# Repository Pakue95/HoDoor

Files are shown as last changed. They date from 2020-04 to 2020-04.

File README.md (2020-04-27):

HoDoor is an access control board that uses RFID (13.56MHz) to authenticate users e.g. to enter restricted areas. The firmware repository can be found [here]() (to be released).

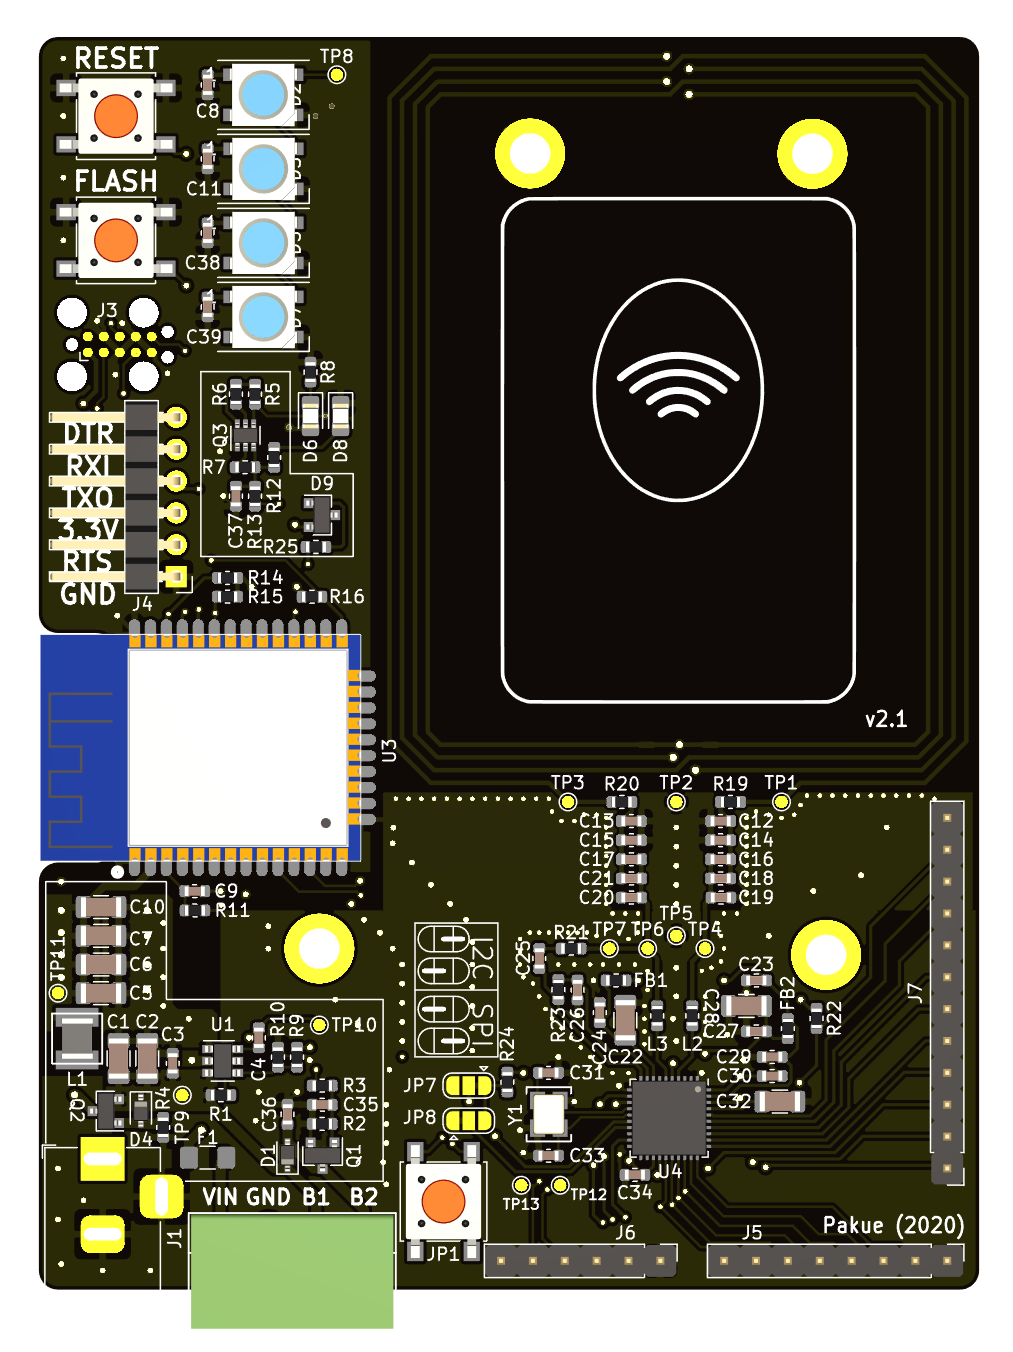
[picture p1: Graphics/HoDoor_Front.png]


## ToDo
* generate Gerber files
* generate new 3d STEP files
* update case-files to v2.1

The work is release as is without any warranties or guarantees. Use on your own risk.

## Hardware
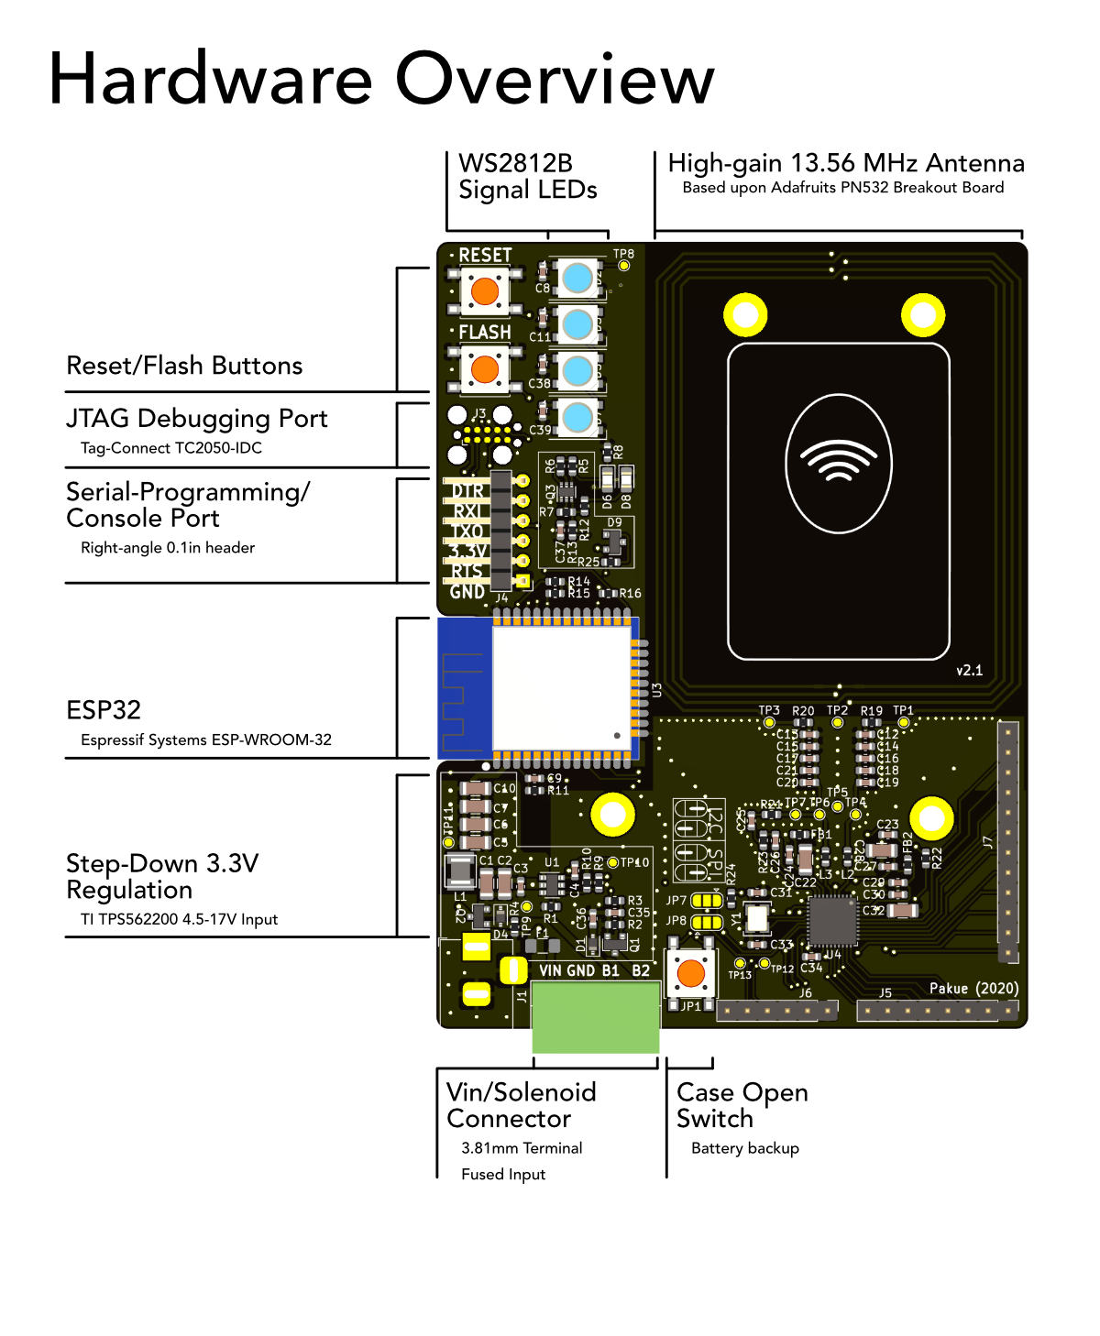
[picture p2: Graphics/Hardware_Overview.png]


## License

Designed by Patrick Kübler (except for Adafruit PN532 Shield part). Creative Commons Attribution/Share-Alike.

### Adafruit PN532 RFID/NFC Shield for Arduino

The NFC part of the board is based upon the Adafruit PN532 RFID/NFC Shield for Arduino. The design files can be found in the according [repository](https://github.com/adafruit/Adafruit-PN532-RFID-NFC-Shield) and the board can be purchased from [Adafruit](https://www.adafruit.com/product/789).

Following changes were made from the Adafruit design:
* Moved pinheader around (no Arduino Shield compatebility anymore)
* Moved some components and routing
* removed LED power indicator
* no prototyping area
* removed 3.3V regulator (handled by the HoDoor board)

**README from Adafruit PN532 Shield**

>We've taken our popular Adafruit PN532 breakout board and turned it into a shield - the perfect tool for any 13.56MHz RFID or NFC application. The Adafruit NFC shield uses the PN532 chip-set (the most popular NFC chip on the market) and is what is embedded in pretty much every phone or device that does NFC. It can pretty much do it all, such as read and write to tags and cards, communicate with phones (say for payment processing), and 'act' like a NFC tag. If you want to do any sort of embedded NFC work, this is the chip you'll want to use!

>These are the Eagle CAD files for the Adafruit PN532 RFID/NFC Shield for Arduino:

>* http://www.adafruit.com/products/789

>License

>Adafruit invests time and resources providing this open source design, please support Adafruit and open-source hardware by purchasing products from Adafruit!

>All text above must be included in any redistribution

>Designed by Limor Fried/Ladyada and Kevin Townsend for Adafruit Industries. Creative Commons Attribution/Share-Alike, all text above must be included in any redistribution. See license.txt for additional information.

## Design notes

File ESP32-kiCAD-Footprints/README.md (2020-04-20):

from [ESP32-kiCAD-Footprints by adamjvr](https://github.com/adamjvr/ESP32-kiCAD-Footprints)

# ESP32-kiCAD-Footprints

Footprints for the Espressif ESP32 WiFi/BLE Chip and ESP3212 module, for KiCAD EDA
These footprints are current untested use at your own risk! I'll have a test board
soon!

Now includes an alternate esp32-xess.lib schematic library in which the
pin types of the ESP32 chip and modules have been changed to reflect their
actual functions (before they were all set as inputs).
This library also includes a symbol for the ESP32 chip that has the pins arranged
like the 48-pin QFN package.

ESP3212 - Module
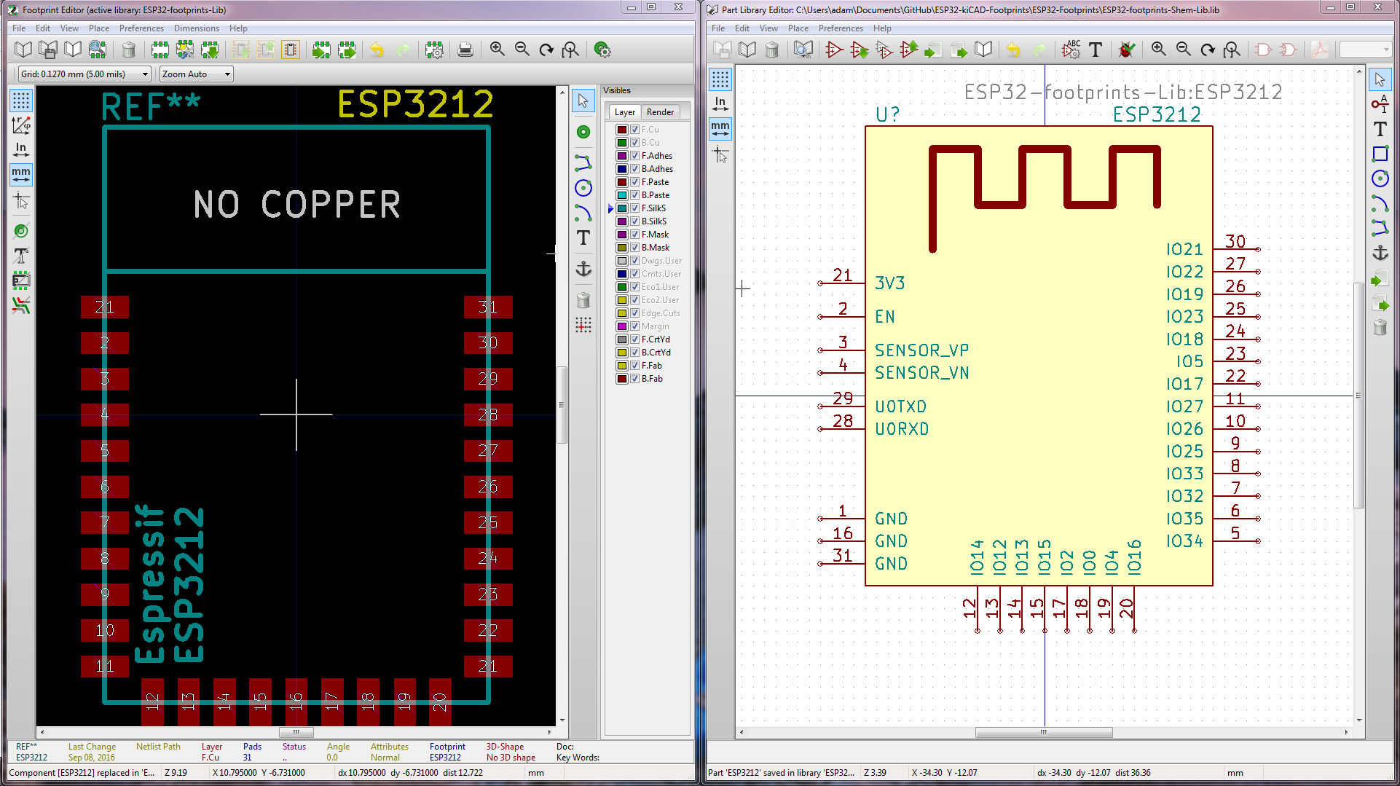
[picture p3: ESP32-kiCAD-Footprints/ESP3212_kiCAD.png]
ESP3212 - Module


ESP32-WROOM - module
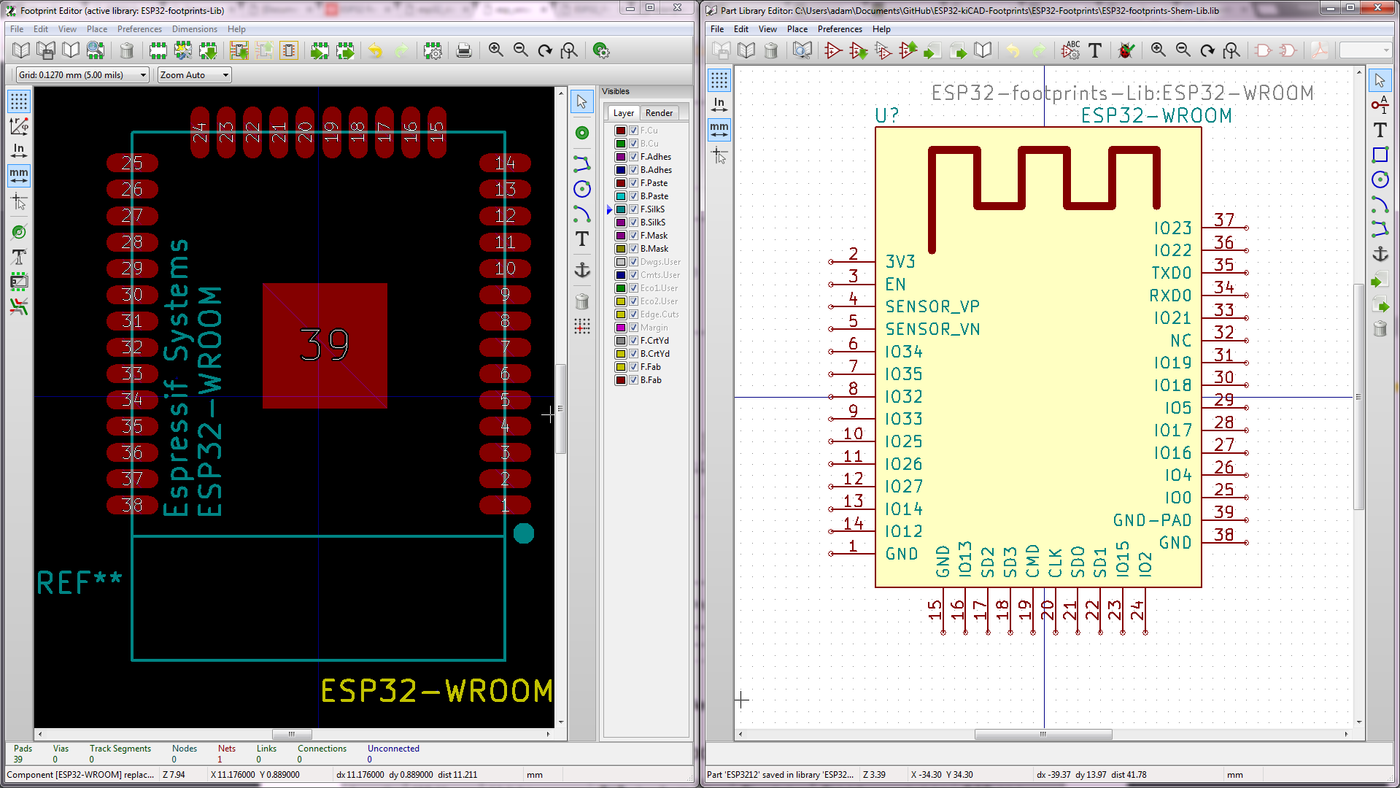
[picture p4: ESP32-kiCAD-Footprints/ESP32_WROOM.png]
ESP32-WROOM - module


ESP32 - 48 Pin QFN IC
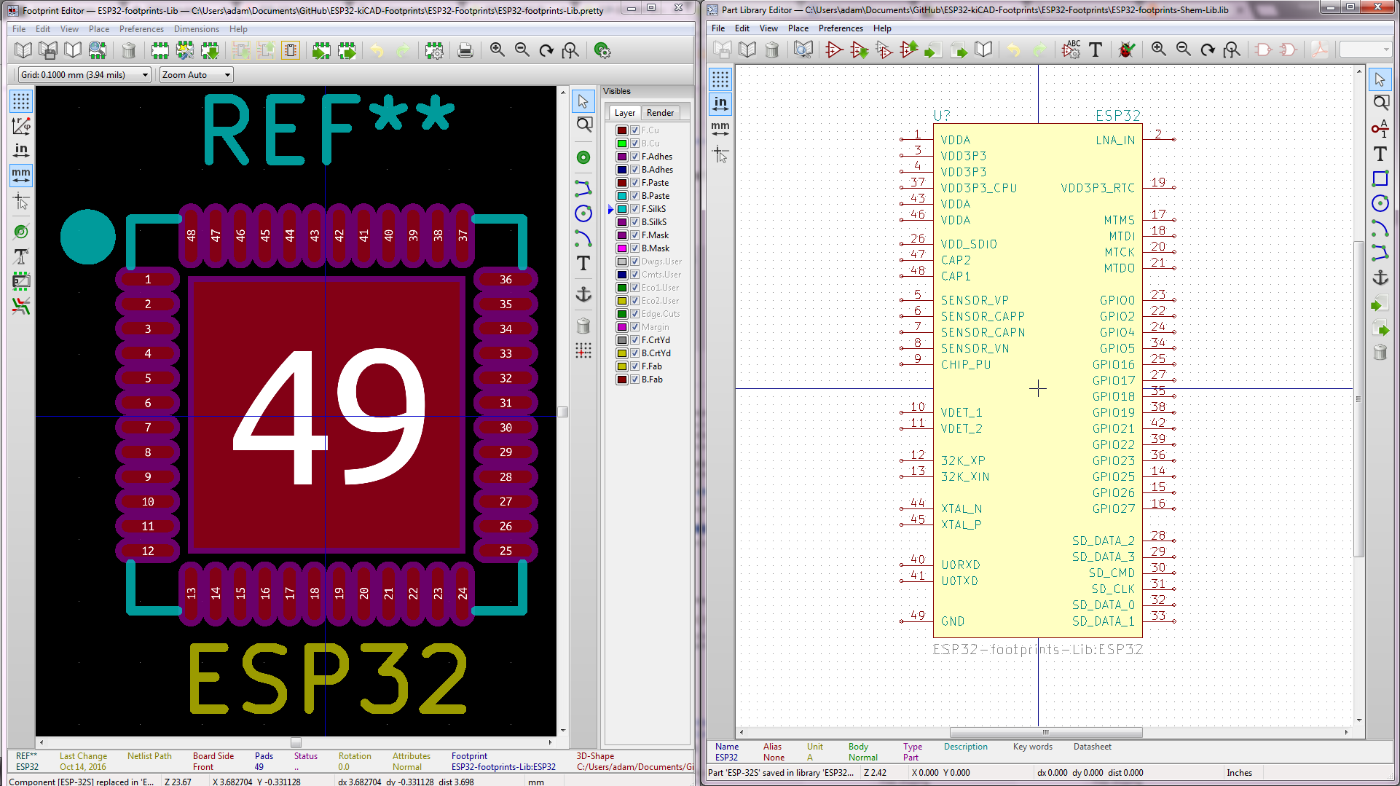
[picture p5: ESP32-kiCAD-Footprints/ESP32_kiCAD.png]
ESP32 - IC


ESP32 - 48 Pin QFN IC (XESS)
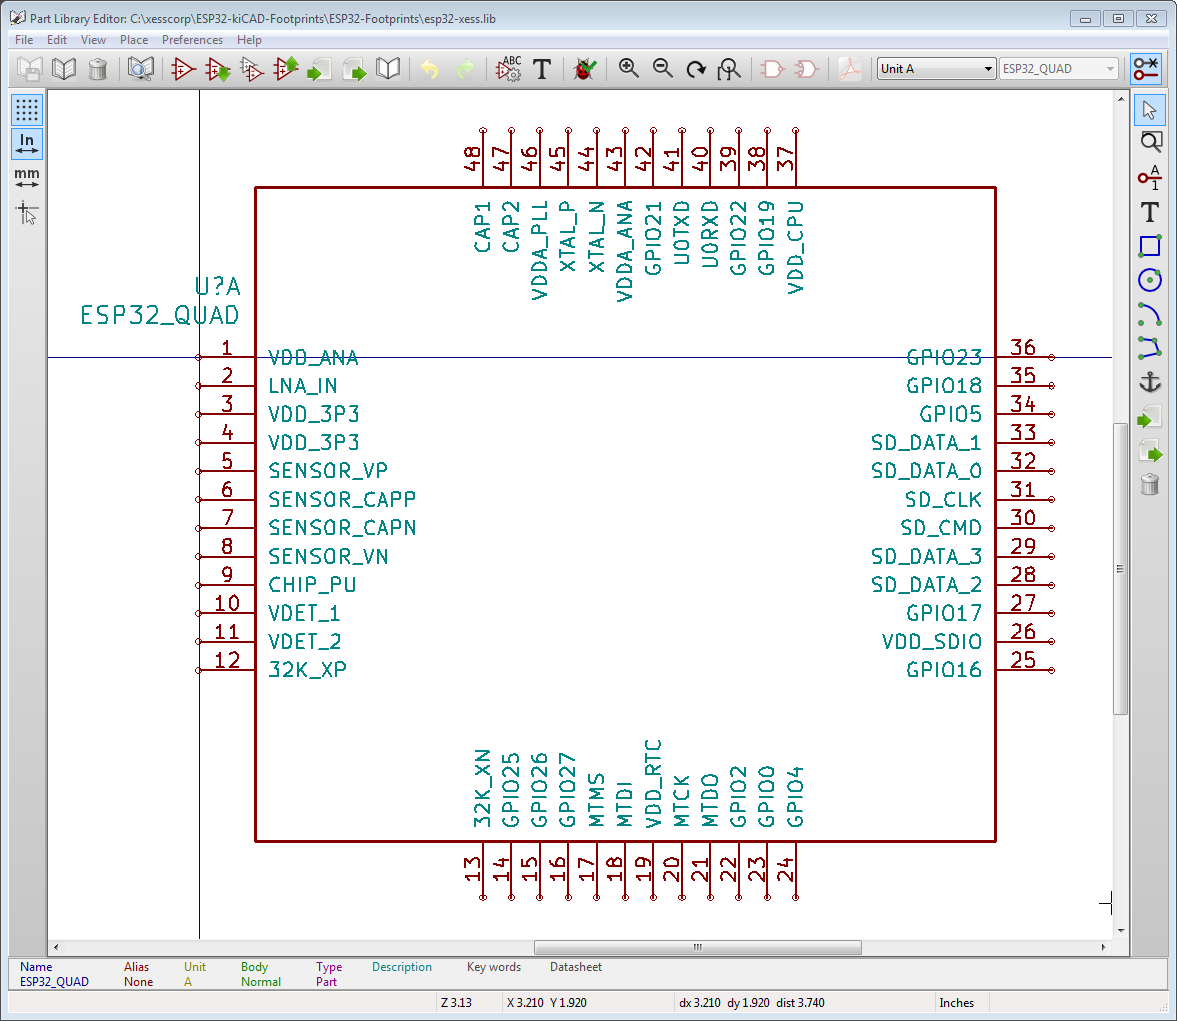
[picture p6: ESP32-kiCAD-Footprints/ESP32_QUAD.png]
ESP32 - IC - XESS


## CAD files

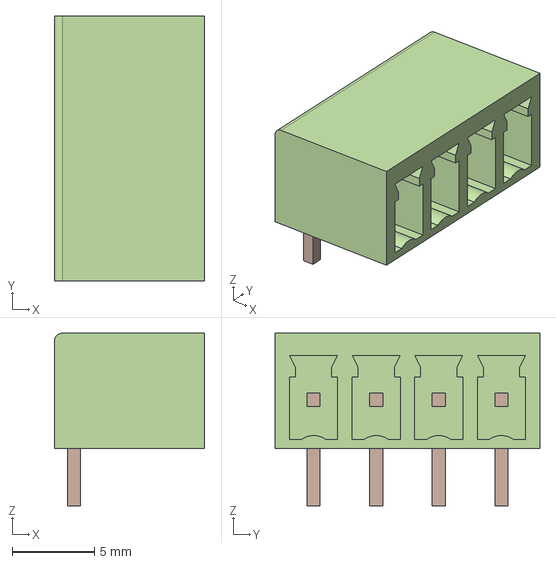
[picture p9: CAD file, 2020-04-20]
3d/WJ15EDGRC-3.81-4P.step
9.15 x 16.1 x 10.5 mm

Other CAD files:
3d/WJ15EDGRC-3.81-4P.FCStd

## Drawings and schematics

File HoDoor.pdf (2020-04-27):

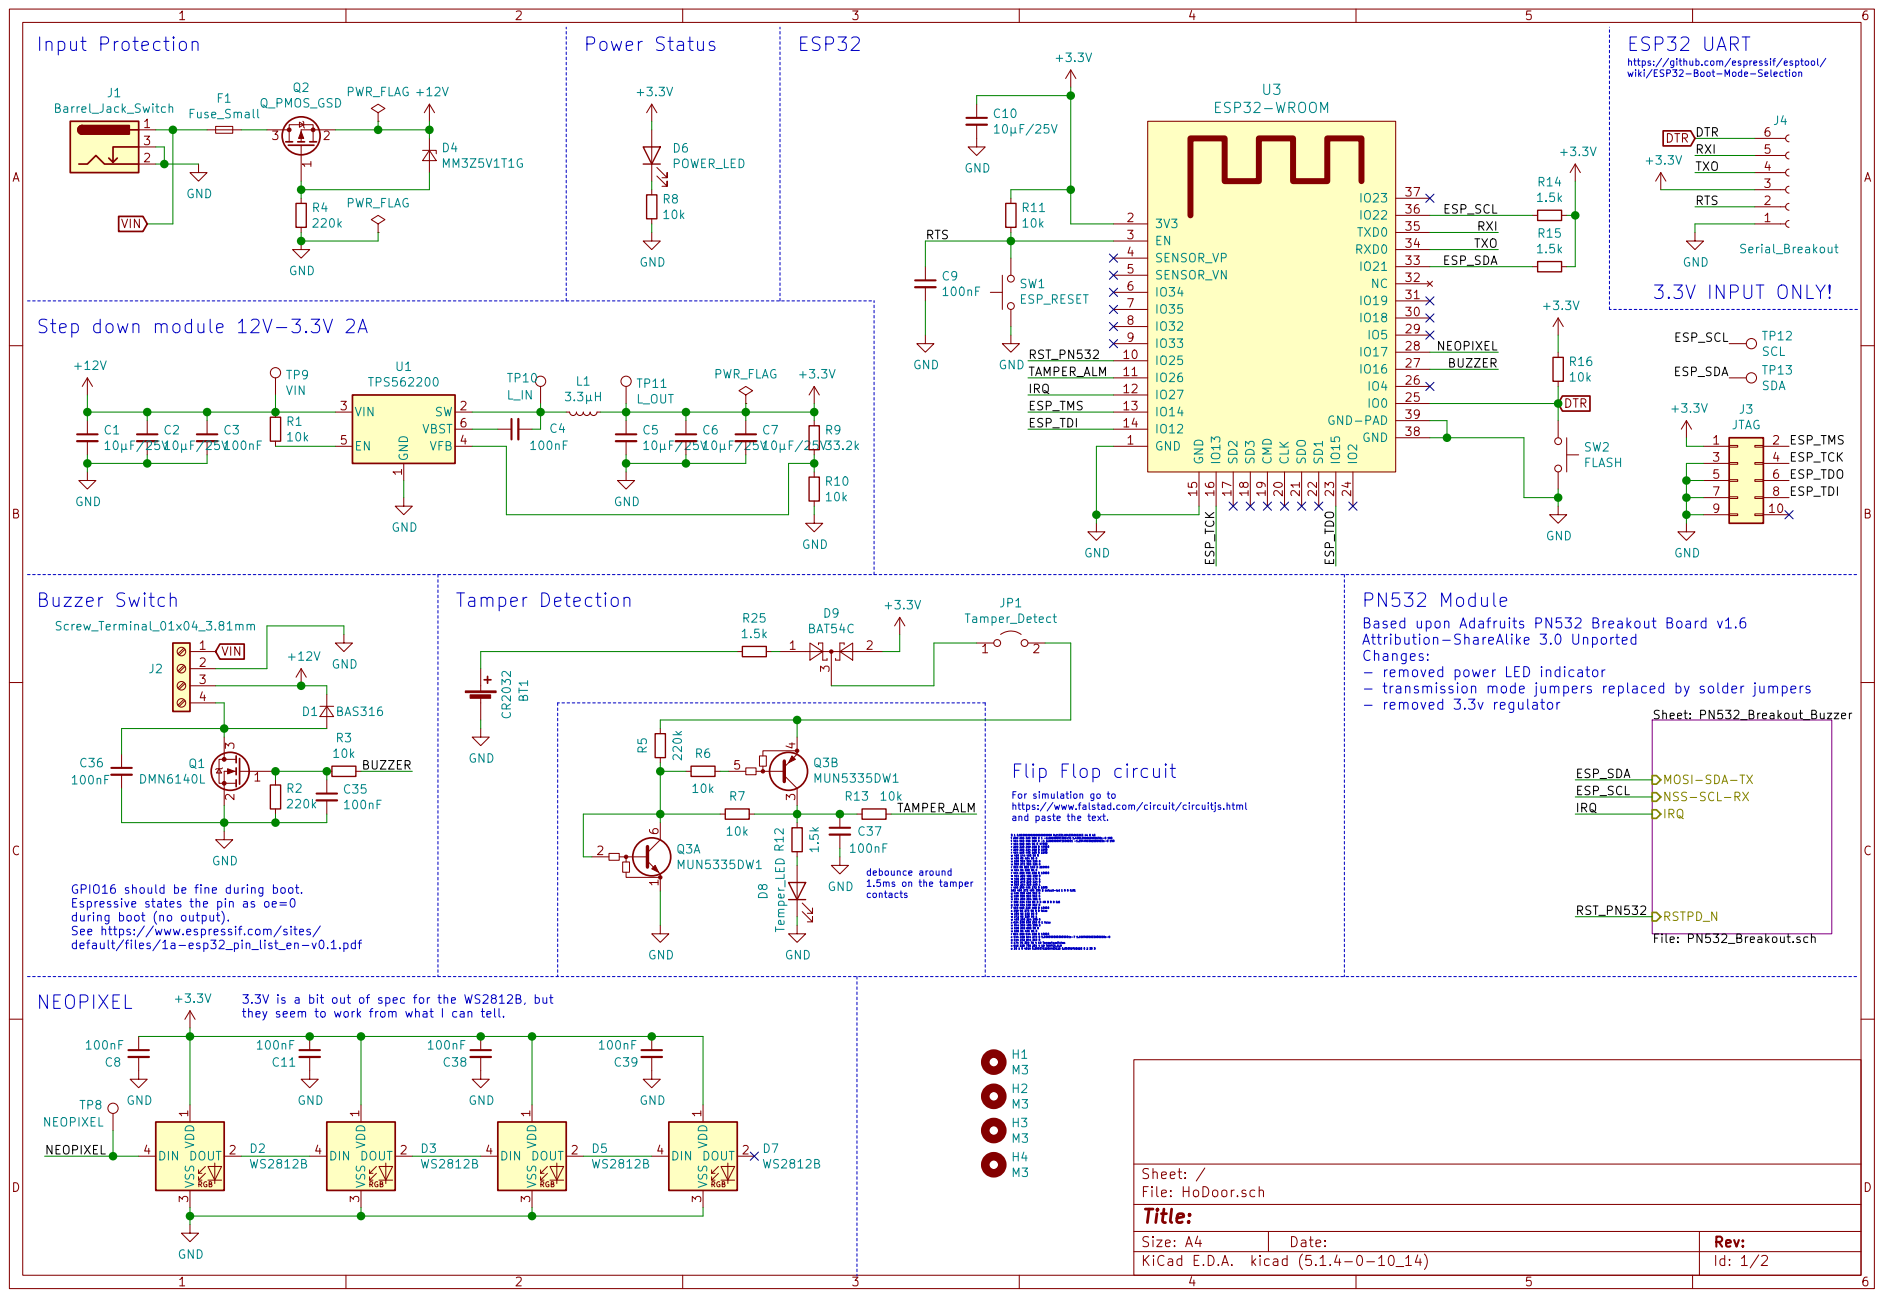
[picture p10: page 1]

https://github.com/espressif/esptool/ wiki/ESP32-Boot-Mode-Selection

debounce around 1.5ms on the tamper contacts Step down module 12V-3.3V 2A

1 SW 2 VIN 3 VFB 4 EN 5 VBST 6 U1 TPS562200 C3

Based upon Adafruits PN532 Breakout Board v1.6
Attribution-ShareAlike 3.0 Unported
Changes:
- removed power LED indicator
- transmission mode jumpers replaced by solder jumpers
- removed 3.3v regulator

For simulation go to https://www.falstad.com/circuit/circuitjs.html and paste the text.

GPIO16 should be fine during boot.
Espressive states the pin as oe=0
during boot (no output).
See https://www.espressif.com/sites/
default/files/1a-esp32_pin_list_en-v0.1.pdf

3.3V is a bit out of spec for the WS2812B, but
they seem to work from what I can tell.

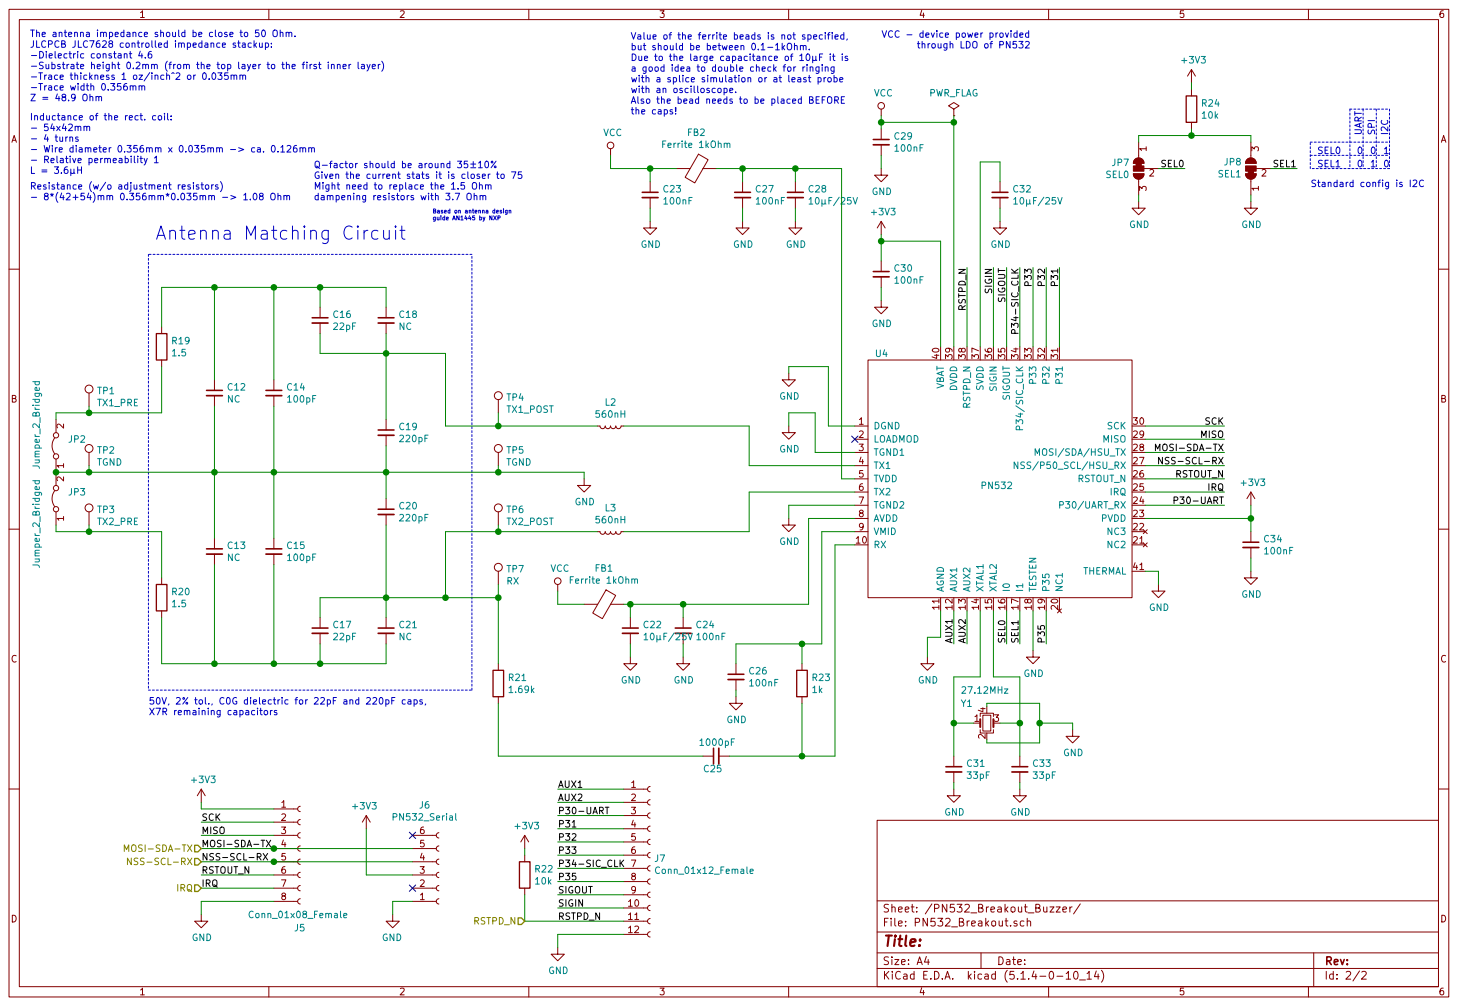
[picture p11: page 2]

Also the bead needs to be placed BEFORE

The antenna impedance should be close to 50 Ohm.
JLCPCB JLC7628 controlled impedance stackup: -Dielectric constant 4.6

Value of the ferrite beads is not specified, but should be between 0.1-1kOhm. Due to the large capacitance of 10µF it is

VCC - device power provided
through LDO of PN532
SEL1 RSTOUT_N

-Substrate height 0.2mm (from the top layer to the first inner layer)
-Trace thickness 1 oz/inch^2 or 0.035mm
-Trace width 0.356mm
Inductance of the rect. coil: - 54x42mm

a good idea to double check for ringing
with a splice simulation or at least probe
with an oscilloscope.

the caps! Based on antenna design guide AN1445 by NXP Q-factor should be around 35±10%

Given the current stats it is closer to 75 Might need to replace the 1.5 Ohm

dampening resistors with 3.7 Ohm

50V, 2% tol., C0G dielectric for 22pF and 220pF caps,
X7R remaining capacitors

SCK MISO MOSI-SDA-TX NSS-SCL-RX RSTOUT_N

IRQ MOSI-SDA-TX

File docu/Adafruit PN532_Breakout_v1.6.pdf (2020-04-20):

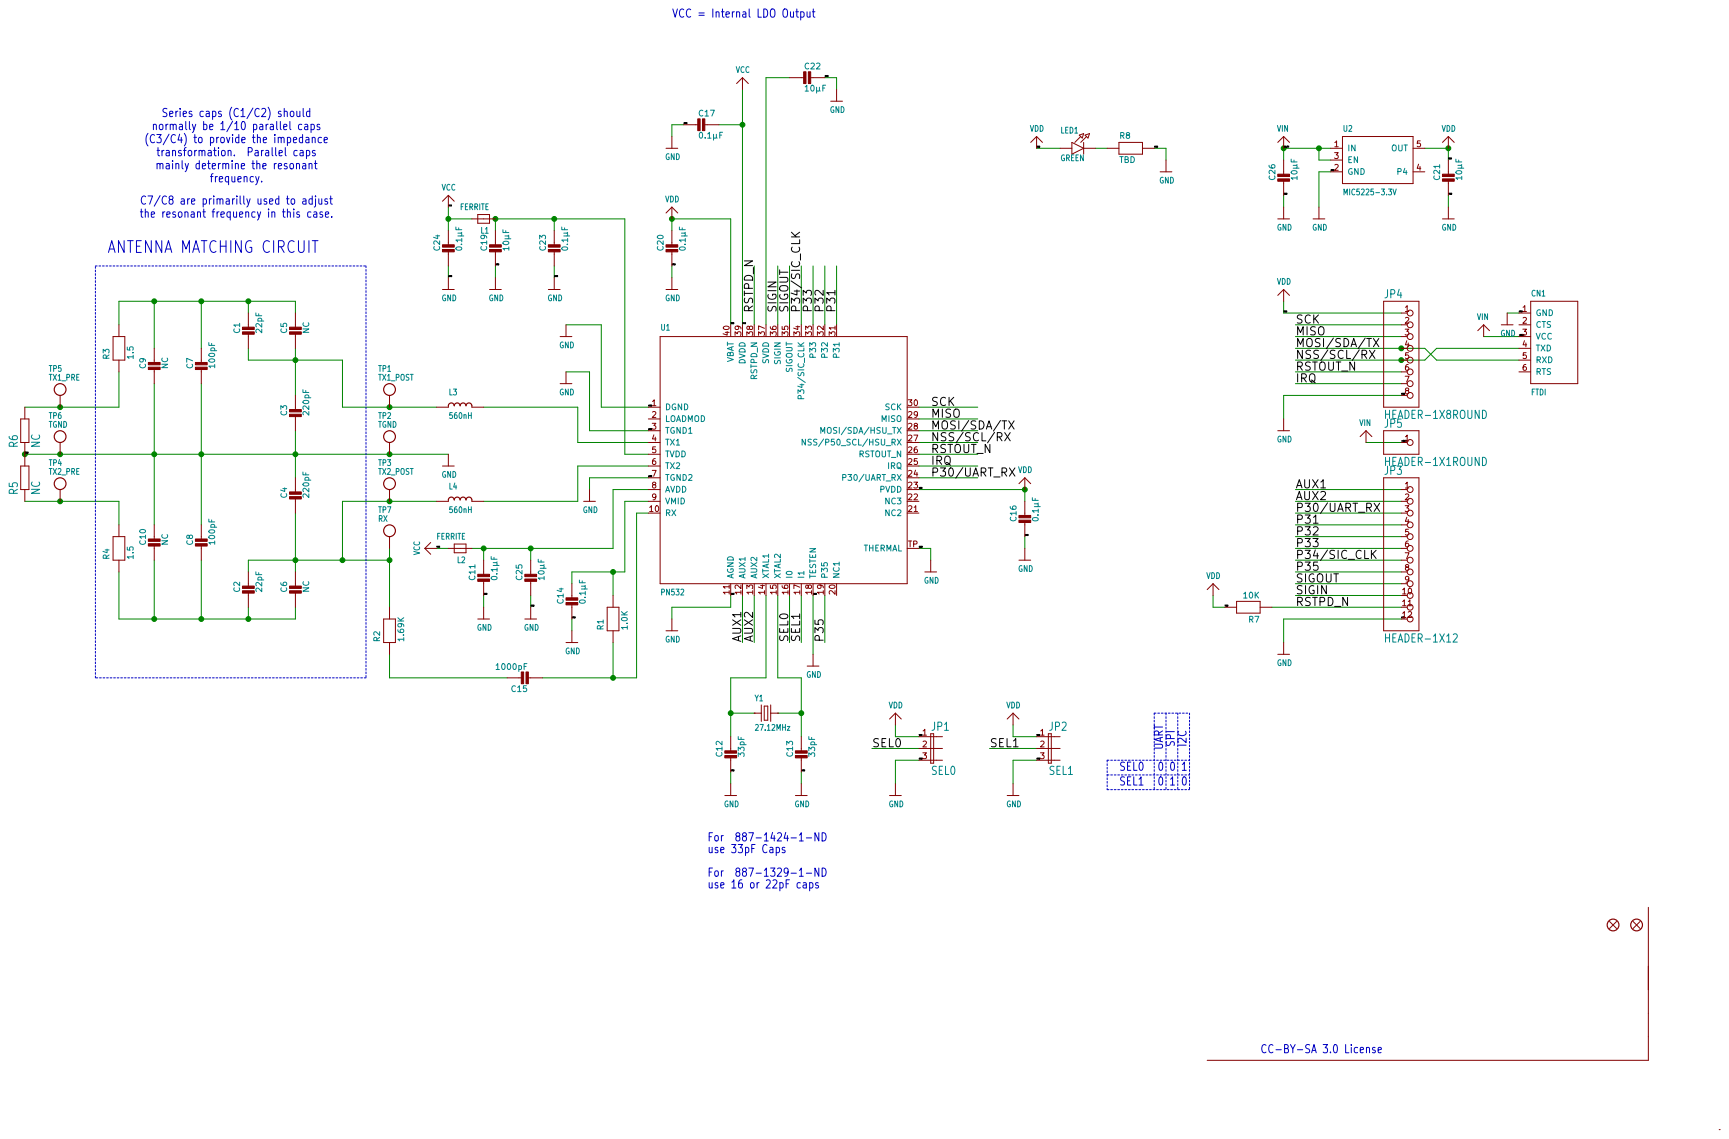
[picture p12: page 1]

VCC = Internal LDO Output

Series caps (C1/C2) should
normally be 1/10 parallel caps
(C3/C4) to provide the impedance
transformation. Parallel caps
mainly determine the resonant

C7/C8 are primarilly used to adjust
the resonant frequency in this case.
ANTENNA MATCHING CIRCUIT

SEL0 | 0 | 0 | 1

CC-BY-SA 3.0 License

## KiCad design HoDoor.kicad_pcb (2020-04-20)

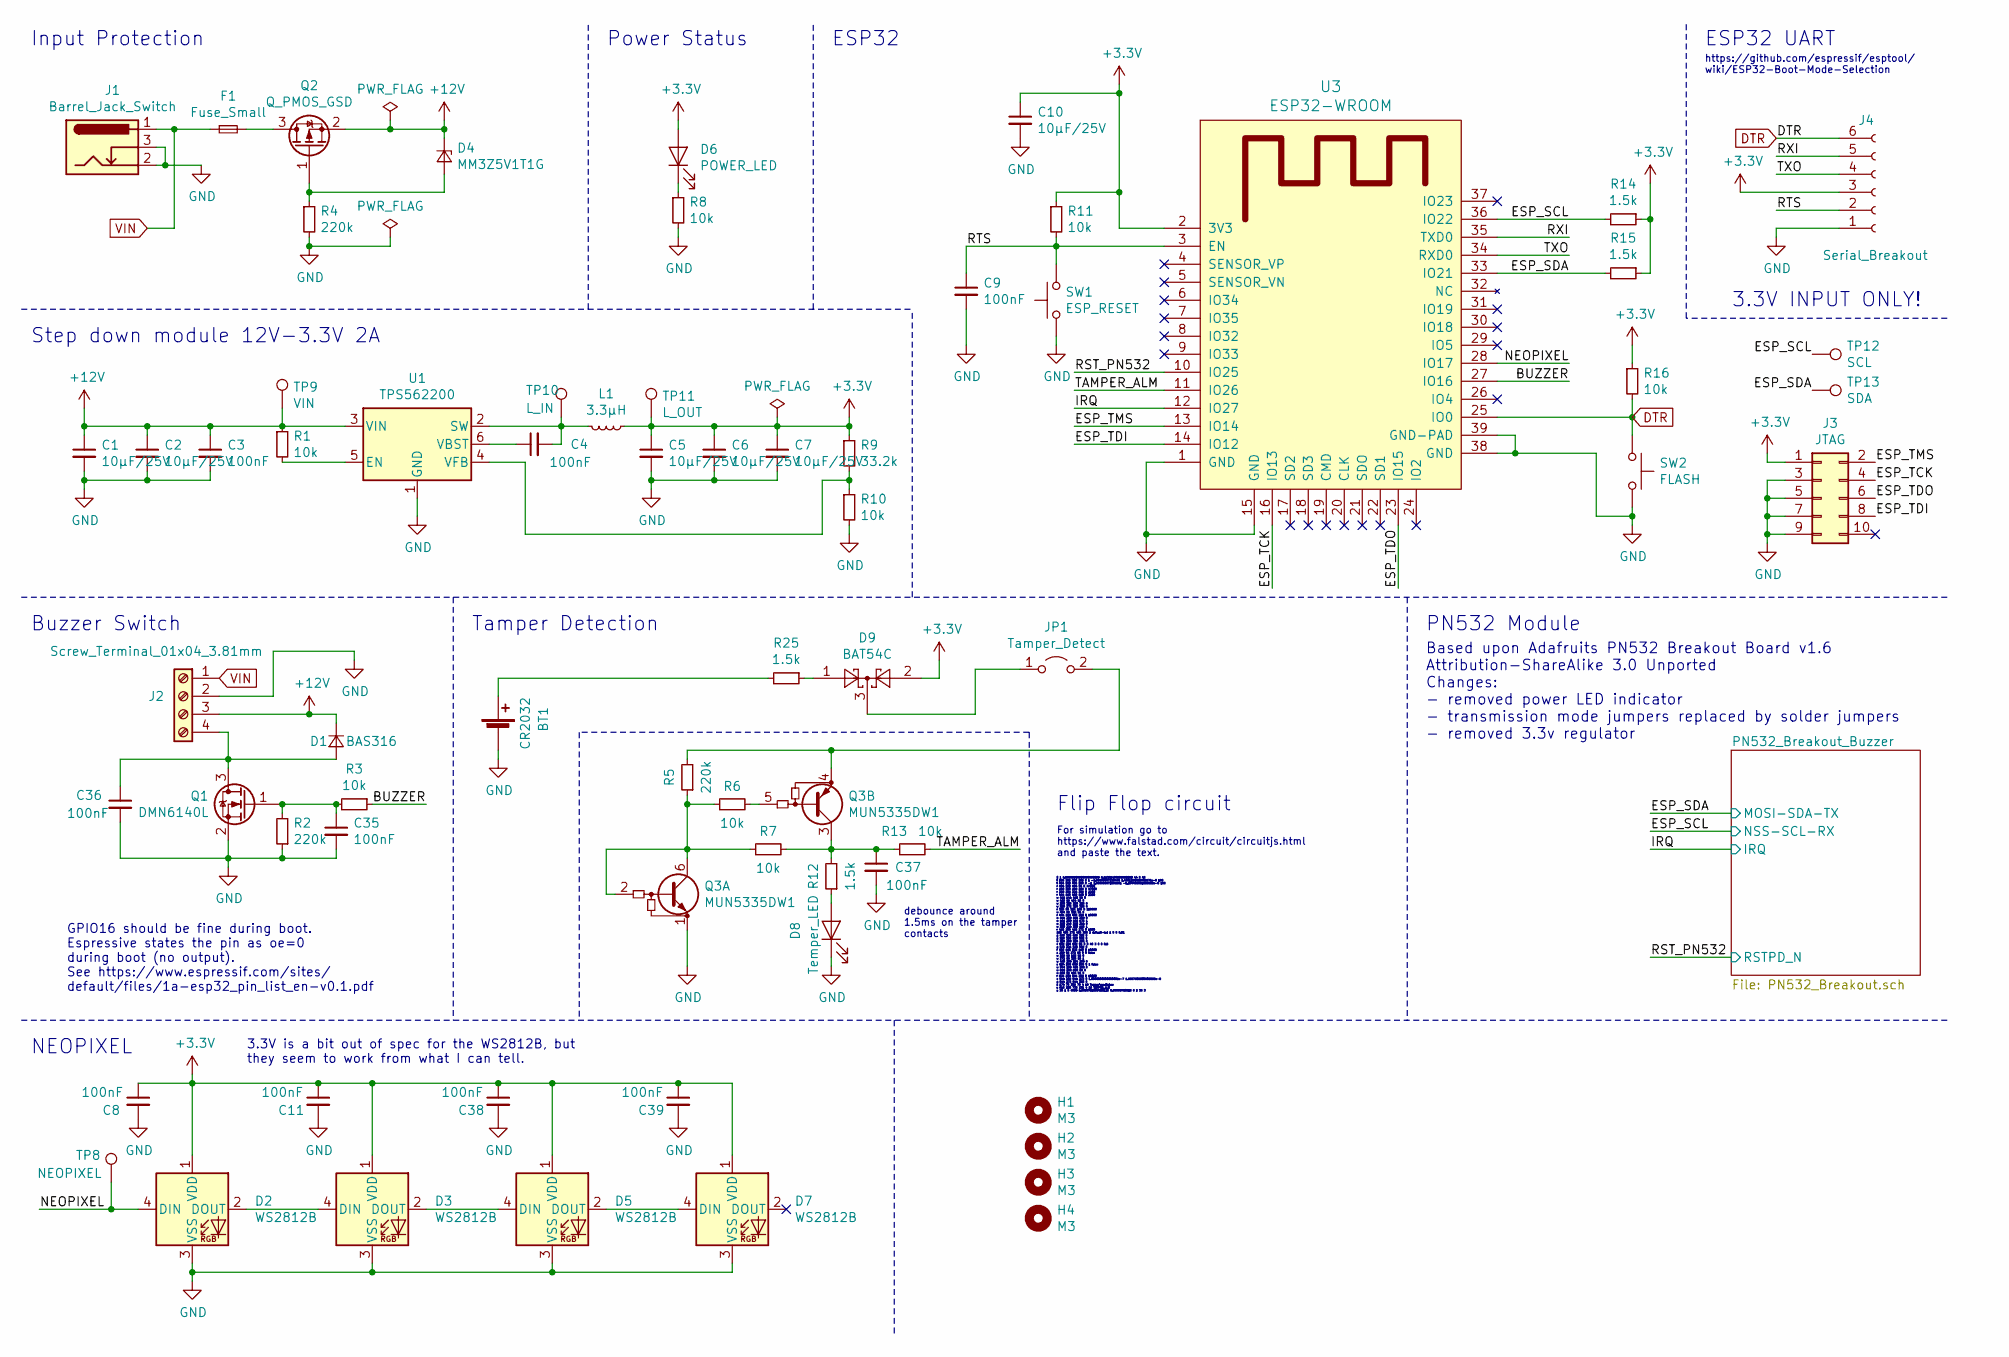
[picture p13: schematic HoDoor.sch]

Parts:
BT1: CR2032; BatteryHolder_Keystone_1060_1x2032; Part CR2032-BS-6-1; LCSC C70377
C1, C2, C5, C6, C7, C10: 10µF/25V; C_1206_3216Metric; Part CL31B106KAHVPNE; LCSC C9807
C3, C4, C8, C9, C11, C35, C36, C37, C38, C39: 100nF; C_0603_1608Metric; Part CL10B104KA8NNNC; LCSC C1590
D1: BAS316; D_SOD-323; Part BAS316,115; LCSC C109218
D2, D3, D5, D7: WS2812B; LED_WS2812B_PLCC4_5.0x5.0mm_P3.2mm
D4: MM3Z5V1T1G; D_SOD-323; Part MM3Z5V1T1G; LCSC C75074
D6: POWER_LED; LED_0805_2012Metric_Pad1.15x1.40mm_HandSolder; Part FC-2012HRK-620D; LCSC C84256
D8: Temper_LED; LED_0805_2012Metric_Pad1.15x1.40mm_HandSolder; Part TJ-S2012SW8TGLC0A-A5 TJ-S2012SW8TGLC0A-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; LCSC C192670
D9: BAT54C; SOT-23; LCSC C37704
F1: Fuse_Small; Fuse_1206_3216Metric_Pad1.42x1.75mm_HandSolder
H1, H2, H3, H4: M3; MountingHole_3.2mm_M3_DIN965_Pad
J1: Barrel_Jack_Switch; BarrelJack_Horizontal
J2: Screw_Terminal_01x04_3.81mm; WJ15EDGRC-3.81-4P; Part WJ15EDGRC-3.81-4P + WJ15EDGKB-3.81-4P; LCSC C7245 + C8408
J3: JTAG; Tag-Connect_TC2050-IDC-FP_2x05_P1.27mm_Vertical
J4: Serial_Breakout; PinHeader_1x06_P2.54mm_Horizontal; Part A2541WR-6P; LCSC C225492
JP1: Tamper_Detect; SW_SPST_B3S-1000
L1: 3.3µH; NPIS43LS; Part NPIS43LS3R3MTRF
Q1: DMN6140L; SOT-23; Part DMN6140LQ-7; LCSC C155271
Q2: Q_PMOS_GSD; SOT-23; Part AO3401A; LCSC C15127
Q3: MUN5335DW1; SOT-363_SC-70-6; Part MUN5335DW1T1G; LCSC C99680
R1, R3, R6, R7, R10, R11, R13, R16: 10k; R_0603_1608Metric; Part RC0603FR-0710KL; LCSC C98220
R2, R4, R5: 220k; R_0603_1608Metric; Part RC0603FR-07220KL; LCSC C123420
R8: 10k; R_0603_1608Metric; Part RC0603JR-07330RL; LCSC C105879
R9: 33.2k; R_0603_1608Metric; Part AC0603FR-0733K2L; LCSC C227824
R12, R14, R15, R25: 1.5k; R_0603_1608Metric; Part RC0603FR-071K5L; LCSC C114668
SW1: ESP_RESET; SW_SPST_B3S-1000; Part TSA063G43-250; LCSC C294564
SW2: FLASH; SW_SPST_B3S-1000; Part TSA063G43-250; LCSC C294564
TP8: NEOPIXEL; TestPoint_Pad_D1.0mm
TP9: VIN; TestPoint_Pad_D1.0mm
TP10: L_IN; TestPoint_Pad_D1.0mm
TP11: L_OUT; TestPoint_Pad_D1.0mm
TP12: SCL; TestPoint_Pad_D1.0mm
TP13: SDA; TestPoint_Pad_D1.0mm
U1: TPS562200; SOT-23-6; Part TPS562200DDCR; LCSC C49757
U3: ESP32-WROOM

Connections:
+12V: C1.1, C2.1, C3.1, D1.1 (K), D4.1 (K), J2.3, Q2.2 (S), R1.1, TP9.1, U1.3 (VIN)
/BUZZER: R3.1, U3.27 (IO16)
/ESP_SCL: R14.2, TP12.1, U3.36 (IO22); also elsewhere on the board
/ESP_SDA: R15.2, TP13.1, U3.33 (IO21); also elsewhere on the board
/ESP_TCK: J3.4, U3.16 (IO13)
/ESP_TDI: J3.8, U3.14 (IO12)
/ESP_TDO: J3.6, U3.23 (IO15)
/ESP_TMS: J3.2, U3.13 (IO14)
/IRQ: U3.12 (IO27); also elsewhere on the board
/NEOPIXEL: D2.4 (DIN), TP8.1, U3.28 (IO17)
/RST_PN532: U3.10 (IO25); also elsewhere on the board
/RTS: C9.1, J4.2, R11.2, SW1.2, U3.3 (EN)
/RXI: J4.5, U3.35 (TXD0)
/TAMPER_ALM: R13.2, U3.11 (IO26)
/TXO: J4.4, U3.34 (RXD0)
DTR: J4.6, R16.2, SW2.1, U3.25 (IO0)
GND: BT1.2 (-), C1.2, C2.2, C3.2, C5.2, C6.2, C7.2, C8.2, C9.2, C10.2, C11.2, C35.2, C36.2, C37.2, C38.2, C39.2, D2.3 (VSS), D3.3 (VSS), D5.3 (VSS), D7.3 (VSS), D8.1 (K), J1.2, J1.3, J2.2, J3.3, J3.5, J3.7, J3.9, J4.1, Q1.2 (S), Q3.1 (E1), R2.1, R4.2, R8.2, R10.2, SW1.1, SW2.2, U1.1 (GND), U3.1 (GND), U3.15 (GND), U3.38 (GND), U3.39 (GND-PAD); also elsewhere on the board
unnamed: BT1.1 (+), R25.2
unnamed: C4.1, U1.6 (VBST)
unnamed: C4.2, L1.2, TP10.1, U1.2 (SW)
unnamed: C35.1, Q1.1 (G), R2.2, R3.2
unnamed: C36.1, D1.2 (A), J2.4, Q1.3 (D)
unnamed: C37.1, Q3.3 (C1), R7.2, R12.2, R13.1
unnamed: D2.2 (DOUT), D3.4 (DIN)
unnamed: D3.2 (DOUT), D5.4 (DIN)
unnamed: D4.2 (A), Q2.1 (G), R4.1
unnamed: D5.2 (DOUT), D7.4 (DIN)
unnamed: D6.1 (K), R8.1
unnamed: D8.2 (A), R12.1
unnamed: D9.1, R25.1
unnamed: D9.3, JP1.1 (A)
unnamed: F1.2, Q2.3 (D)
unnamed: JP1.2 (B), Q3.4 (E1), R5.2
unnamed: Q3.2 (B1), Q3.6 (C1), R5.1, R6.1, R7.1
unnamed: Q3.5 (B1), R6.2
unnamed: R1.2, U1.5 (EN)
unnamed: R9.2, R10.1, U1.4 (VFB)
VIN: F1.1, J1.1, J2.1

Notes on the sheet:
Step down module 12V-3.3V 2A
GPIO16 should be fine during boot. Espressive states the pin as oe=0 during boot (no output). See https://www.espressif.com/sites/ default/files/1a-esp32_pin_list_en-v0.1.pdf
3.3V INPUT ONLY!
Input Protection
Power Status
Buzzer Switch
Tamper Detection
PN532 Module
ESP32 UART
NEOPIXEL
https://github.com/espressif/esptool/ wiki/ESP32-Boot-Mode-Selection
$ 1 0.00009999999999999999 0.11331484530668263 44 5 43 t 288 256 320 256 0 1 -2.99999997233476 1.4381236668005676e-8 100 t 464 160 496 160 0 -1 2.999999971598301 -1.154406081838033e-8 100 r 464 160 464 96 0 47000 r 288 320 288 256 0 47000 r 288 256 224 256 0 2200 r 464 160 400 160 0 2200 w 496 144 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
For simulation go to https://www.falstad.com/circuit/circuitjs.html and paste the text.
ESP32
Flip Flop circuit
debounce around 1.5ms on the tamper contacts
3.3V is a bit out of spec for the WS2812B, but they seem to work from what I can tell.
Based upon Adafruits PN532 Breakout Board v1.6 Attribution-ShareAlike 3.0 Unported Changes: - removed power LED indicator - transmission mode jumpers replaced by solder jumpers - removed 3.3v regulator

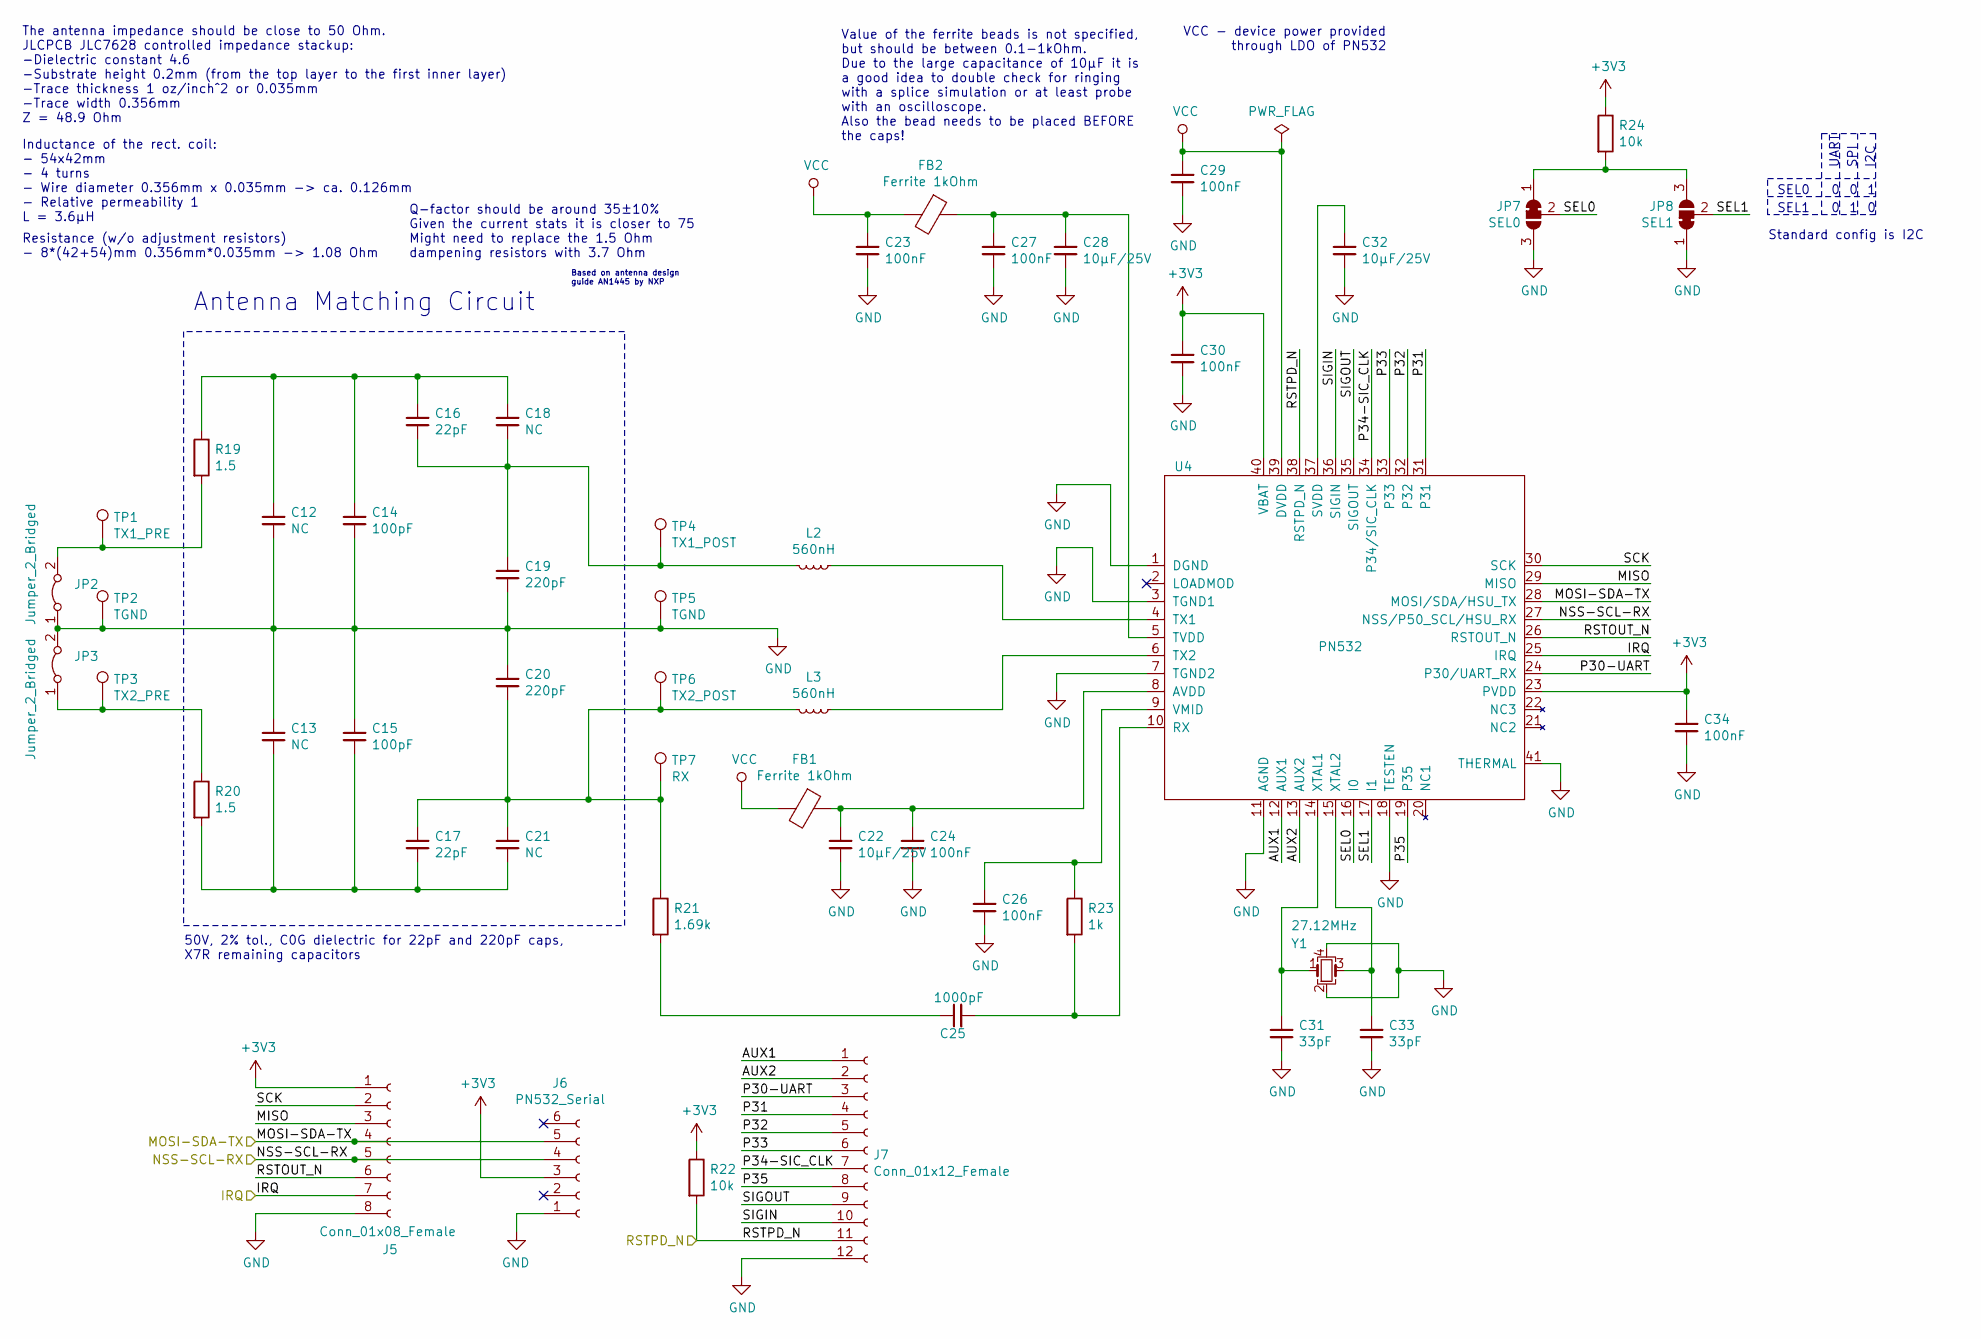
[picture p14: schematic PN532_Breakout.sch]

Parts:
C12, C13, C18, C21: NC; C_0603_1608Metric
C14, C15: 100pF; C_0603_1608Metric; Part CC0603GRNPO9BN221; LCSC C327167
C16, C17: 22pF; C_0603_1608Metric; Part CC0603FRNPO9BN220; LCSC C326840
C19, C20: 220pF; C_0603_1608Metric; Part CC0603GRNPO9BN221; LCSC C327167
C22, C28, C32: 10µF/25V; C_1206_3216Metric; Part CL31B106KAHVPNE; LCSC C9807
C23, C24, C26, C27, C29, C30, C34: 100nF; C_0603_1608Metric; Part CL10B104KA8NNNC; LCSC C1590
C25: 1000pF; C_0603_1608Metric; Part CL10C102JB8NNNC; LCSC C163508
C31, C33: 33pF; C_0603_1608Metric; Part CL10C330JB8NNNC; LCSC C1663
FB1, FB2: Ferrite 1kOhm; R_0603_1608Metric; Part CBW160808U102T; LCSC C50069
J5: Conn_01x08_Female; PinHeader_1x08_P2.54mm_Vertical
J6: PN532_Serial; PinHeader_1x06_P2.54mm_Vertical
J7: Conn_01x12_Female; PinHeader_1x12_P2.54mm_Vertical
JP2, JP3: Jumper_2_Bridged; NetTie-2_SMD_Pad0.5mm
JP7: SEL0; SolderJumper-3_P1.3mm_Bridged12_RoundedPad1.0x1.5mm_DRCfix
JP8: SEL1; SolderJumper-3_P1.3mm_Bridged12_RoundedPad1.0x1.5mm_DRCfix
L2, L3: 560nH; R_0603_1608Metric; Part MLJ1608WR56JT000; LCSC C83787
R19, R20: 1.5; R_0603_1608Metric; Part RC0603FR-071R5L; LCSC C245932
R21: 1.69k; R_0603_1608Metric; Part AC0603FR-071K69L; LCSC C227658
R22, R24: 10k; R_0603_1608Metric; Part RC0603FR-0710KL; LCSC C98220
R23: 1k; R_0603_1608Metric; Part RC0603FR-071KL; LCSC C22548
TP1: TX1_PRE; TestPoint_Pad_D1.0mm
TP2, TP5: TGND; TestPoint_Pad_D1.0mm
TP3: TX2_PRE; TestPoint_Pad_D1.0mm
TP4: TX1_POST; TestPoint_Pad_D1.0mm
TP6: TX2_POST; TestPoint_Pad_D1.0mm
TP7: RX; TestPoint_Pad_D1.0mm
U4: PN532; QFN-40-1EP_6x6mm_P0.5mm_EP4.6x4.6mm; Part PN5321A3HN/C106,55; LCSC C28925
Y1: 27.12MHz; 7M-27.120MAAJ-T; Part 7M-27.120MAAJ-T; LCSC C70591

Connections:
/ESP_SCL: J5.5, J6.4, U4.27 (NSS/P50_SCL/HSU_RX); also elsewhere on the board
/ESP_SDA: J5.4, J6.5, U4.28 (MOSI/SDA/HSU_TX); also elsewhere on the board
/IRQ: J5.7, U4.25 (IRQ); also elsewhere on the board
/PN532_Breakout_Buzzer/AUX1: J7.1, U4.12 (AUX1)
/PN532_Breakout_Buzzer/AUX2: J7.2, U4.13 (AUX2)
/PN532_Breakout_Buzzer/MISO: J5.3, U4.29 (MISO)
/PN532_Breakout_Buzzer/P30-UART: J7.3, U4.24 (P30/UART_RX)
/PN532_Breakout_Buzzer/P31: J7.4, U4.31
/PN532_Breakout_Buzzer/P32: J7.5, U4.32
/PN532_Breakout_Buzzer/P33: J7.6, U4.33
/PN532_Breakout_Buzzer/P34-SIC_CLK: J7.7, U4.34 (P34/SIC_CLK)
/PN532_Breakout_Buzzer/P35: J7.8, U4.19 (P35)
/PN532_Breakout_Buzzer/RSTOUT_N: J5.6, U4.26 (RSTOUT_N)
/PN532_Breakout_Buzzer/SCK: J5.2, U4.30 (SCK)
/PN532_Breakout_Buzzer/SEL0: JP7.2 (C), U4.16 (I0)
/PN532_Breakout_Buzzer/SEL1: JP8.2 (C), U4.17 (I1)
/PN532_Breakout_Buzzer/SIGIN: J7.10, U4.36 (SIGIN)
/PN532_Breakout_Buzzer/SIGOUT: J7.9, U4.35 (SIGOUT)
/RST_PN532: J7.11, R22.2, U4.38 (RSTPD_N); also elsewhere on the board
GND: C12.2, C13.1, C14.2, C15.1, C19.2, C20.1, C22.2, C23.2, C24.2, C26.2, C27.2, C28.2, C29.2, C30.2, C31.2, C32.2, C33.2, C34.2, J5.8, J6.1, J7.12, JP2.1 (A), JP3.2 (B), JP7.3 (B), JP8.1 (A), TP2.1, TP5.1, U4.1 (DGND), U4.3 (TGND1), U4.7 (TGND2), U4.11 (AGND), U4.18 (TESTEN), U4.41 (THERMAL), Y1.2, Y1.4; also elsewhere on the board
unnamed: C12.1, C14.1, C16.1, C18.1, R19.1
unnamed: C13.2, C15.2, C17.2, C21.2, R20.2
unnamed: C16.2, C18.2, C19.1, L2.2, TP4.1
unnamed: C17.1, C20.2, C21.1, L3.2, R21.1, TP6.1, TP7.1
unnamed: C22.1, C24.1, FB1.1, U4.8 (AVDD)
unnamed: C25.1, R21.2
unnamed: C25.2, R23.2, U4.10 (RX)
unnamed: C26.1, R23.1, U4.9 (VMID)
unnamed: C27.1, C28.1, FB2.1, U4.5 (TVDD)
unnamed: C31.1, U4.14 (XTAL1), Y1.1
unnamed: C32.1, U4.37 (SVDD)
unnamed: C33.1, U4.15 (XTAL2), Y1.3
unnamed: JP2.2 (B), R19.2, TP1.1
unnamed: JP3.1 (A), R20.1, TP3.1
unnamed: JP7.1 (A), JP8.3 (B), R24.2
unnamed: L2.1, U4.4 (TX1)
unnamed: L3.1, U4.6 (TX2)
VCC: C23.1, C29.1, FB1.2, FB2.2, U4.39 (DVDD)

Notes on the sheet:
VCC - device power provided through LDO of PN532
Value of the ferrite beads is not specified, but should be between 0.1-1kOhm. Due to the large capacitance of 10µF it is a good idea to double check for ringing with a splice simulation or at least probe with an oscilloscope. Also the bead needs to be placed BEFORE the caps!
SEL0
SEL1
UART
SPI
I2C
Antenna Matching Circuit
Standard config is I2C
50V, 2% tol., C0G dielectric for 22pF and 220pF caps, X7R remaining capacitors
The antenna impedance should be close to 50 Ohm. JLCPCB JLC7628 controlled impedance stackup: -Dielectric constant 4.6 -Substrate height 0.2mm (from the top layer to the first inner layer) -Trace thickness 1 oz/inch^2 or 0.035mm -Trace width 0.356mm Z = 48.9 Ohm
Inductance of the rect. coil: - 54x42mm - 4 turns - Wire diameter 0.356mm x 0.035mm -> ca. 0.126mm - Relative permeability 1 L = 3.6µH
Resistance (w/o adjustment resistors) - 8*(42+54)mm 0.356mm*0.035mm -> 1.08 Ohm
Q-factor should be around 35±10% Given the current stats it is closer to 75 Might need to replace the 1.5 Ohm dampening resistors with 3.7 Ohm
Based on antenna design guide AN1445 by NXP

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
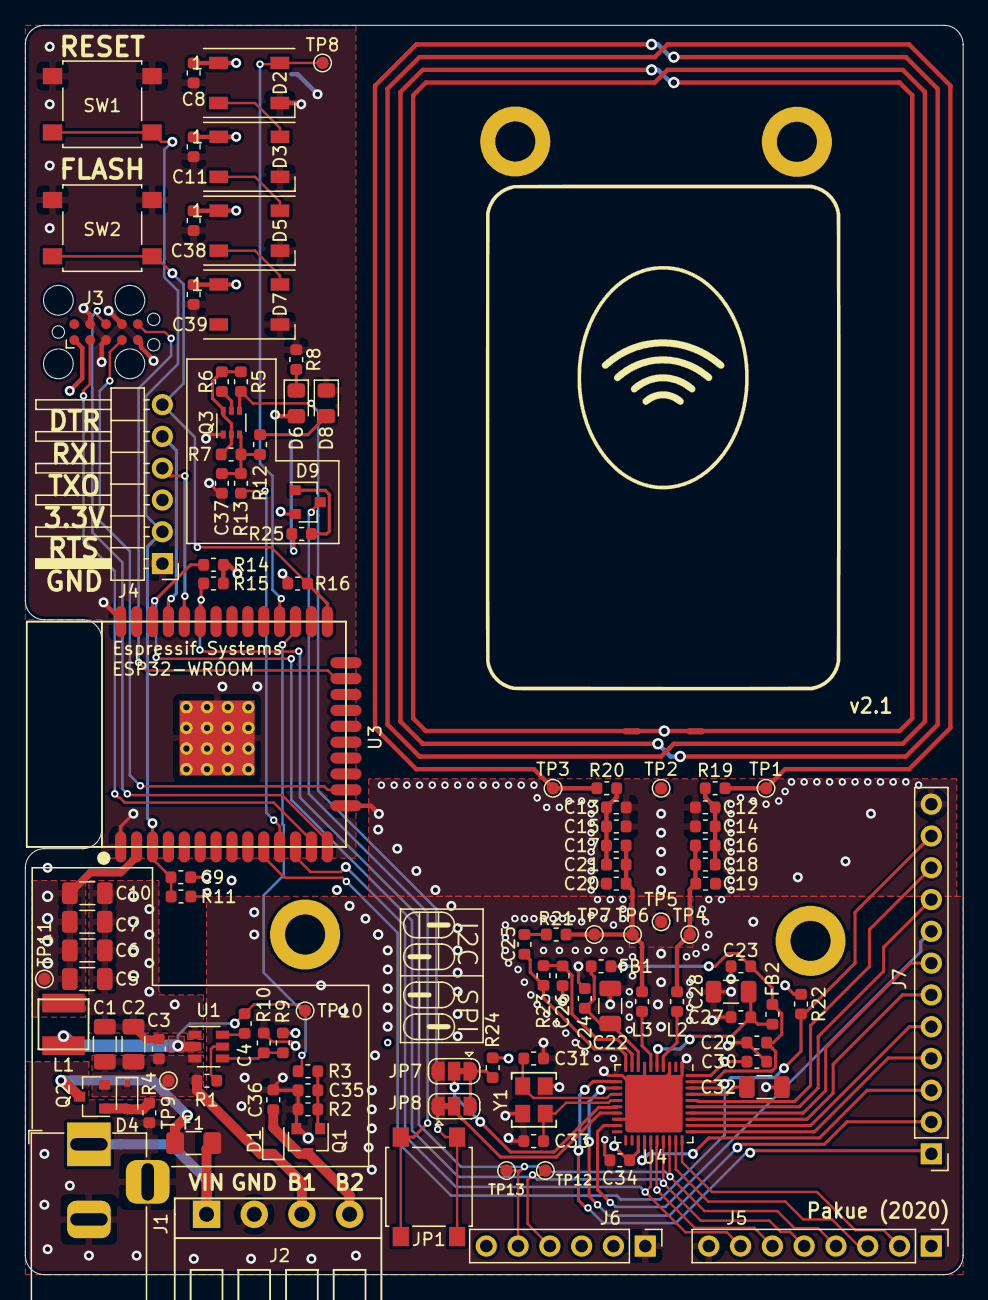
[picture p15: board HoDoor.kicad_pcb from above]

Board: 4 copper layers, 74.9 x 99.8 mm, 116 parts (1 on the bottom side), 72 nets.

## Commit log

2020-04-20 inital project files port
    [ESP32-Footprints.kicad_pcb, ESP32-Footprints.sch, HoDoor.kicad_pcb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]
2020-04-27 added schematic pdf and STEP file of the board
